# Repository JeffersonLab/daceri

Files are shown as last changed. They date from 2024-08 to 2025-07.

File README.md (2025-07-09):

# robot-project
Any and all code for the DACERI (DAta CEnter Robot Inspector) project in affiliation with Jefferson Lab.

## Example Video
[Demonstration of the Robot](https://www.youtube.com/watch?v=JDuZJEAZcf4&t=47s)

## Links
- [Parts List](https://docs.google.com/spreadsheets/d/1oFqTVsd3Hdgb1OTtmRurlVj-2fMQM05GRbAsK3FwgG0/edit?usp=sharing)
- [Thesis](https://drive.google.com/file/d/1kZYvtbdwQk6LjgCDchcMXePofmcdOxIe/view?usp=sharing)

## Run Simulation
1. Download the respective file based on OS and architecture: [https://github.com/google-deepmind/mujoco/releases](https://github.com/google-deepmind/mujoco/releases/latest)
2. Extract the file, and run **simulate** inside the extracted folder. Mujoco simulator should run
3. Clone this repository
4. Go into the **sim/** directory
5. Drag-and-drop any .xml into the simulator

## Edit/Print 3D model parts
1. Clone this repository
2. Go into the **designs/** directory
3. Choose any design you'd like
4. Open in any CAD software, make changes, and export as STL
5. Use a program like [UltiMaker Cura](https://ultimaker.com/software/ultimaker-cura/) or [Prusa Slicer](https://github.com/prusa3d/PrusaSlicer/releases) and slice the STL file into GCODE
6. Run the GCODE file on a 3D printer

## Move the robot
1. Clone this repository on both the client computer and the robot's R-Pi
2. On the robot's R-Pi, run the following steps according to your desired setup:
   * Run this first:
     ```
     python -m venv ./.venv --system-site-packages
     pip install -r /path/to/daceri/libs/requirements.txt
     source ./.venv/bin/activate
     ```
   * UDP Server (Modify the IP Address in the udp-server.py file to the IP of the R-Pi):
     ```
     python /path/to/daceri/scripts/udp-server.py
     ```
   * Websockets Server:
     ```
     python /path/to/daceri/scripts/websockets.py
     ```
4. Go into the **scripts/** directory
5. Use the provided Dockerfile ([Wiki: How to download and install Docker](https://docs.docker.com/get-started/get-docker/)) to automatically setup the correct packages and libraries or use a Linux/MacOS system with Python installed
   * Container:
     ```
     cd ./robot-project
     docker build -t robot-container .
     docker run -v `pwd`:/work/robot:Z -v /dev/input:/dev/input:ro --rm -it robot-container:latest
     ```
   * Host System (Linux/MacOS):
     ```
     python -m venv --system-site-packages ./.venv
     source ./.venv/bin/activate
     pip install -r /path/to/daceri/libs/requirements.txt
     ```
4. Plug in a controller (OS-dependent; usually [Linux](https://www.linuxmint.com/) works the best)
5. Run the RobotController.py file (under the **scripts/** subdirectory) with the desired connection type:
   * Serial (Controller is plugged into the Raspberry Pi):
     ```
     python RobotController.py s
     ```
   * Websockets:
     ```
     python RobotController.py w [R-Pi IPv4 address]
     ```
   * UDP Sockets:
     ```
     python RobotController.py u [R-Pi IPv4 address]
     ```
7. Press the **right** joystick to activate the motors
8. Start moving the joysticks to move the robot!

Use the Logitech F310 Game Controller connected to the local RaspPi 4B and control the JLab DACERI robot with the [REV Control Hub](https://www.revrobotics.com/rev-31-1595/).

## External Modules
```bash
git submodule update --init  # Clone the submodules
```

- `hiddapi`: The underlying system-level support for python package `hid`. After `dnf/apt install hid`, if you still see the python import error such as cannot find certain *.so/*.dll files, you will need to compile and install the `hidapi` library by your self. Follow the docstrings in [detect_joystick.py](./scripts/detect_joystick.py) to see the process.

- `REVHubInterface`: The Python module for the REV Control Hub. By running `python -m REVHubInterface`, you should be able to see a GUI that can take the inputs from the GUI and control the Robot motors.

## Scripts
- [motor_test.py](./scripts/motor_test.py): Control one of the wheels (motors) with `REVHubInterface` without launching the GUI. If succeeded, the wheel will run for 3 seconds.
- [detect_joystick.py](./scripts/detect_joystick.py): Use the Python `hid` library to detect the Logitech F310 Game Controller, translate its inputs to a string and print the string to the screen.

### Notes
#### **Fix the `/dev/hidraw*` permission**

If you can print the gampad's vendor id and product id to the screen but it raises `HIDException` "Unable to open device", that is related to the permission for the device.

Check it with `ls -l /dev/hidraw*` (`hidraw1` in our case). If it’s owned by `root` or another group, the user can’t access it. Fix it by:

1. Create a udev rule: `sudo nano /etc/udev/rules.d/99-logitech-f310.rules`
2. In this rule file, add:
    ```
    SUBSYSTEM=="hidraw", ATTRS{idVendor}=="046d", ATTRS{idProduct}=="c216", MODE="0666"
    ```
   Replace the `idVendor` and `idProduct` with the HEX outputs of the Python file.
3. Reload the rule
    ```bash
    sudo udevadm control --reload
    sudo udevadm trigger
    ```

Rerun the Python script and the `HIDException` error should be gone.

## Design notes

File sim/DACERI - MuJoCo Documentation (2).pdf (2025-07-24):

# MujoCo Documentation and Guide for Project DACERI

Evan Xu

## Overview

This document serves as a guide to using the MuJoCo simulation software, particularly as it

applies to the DACERI project.

MuJoCo is an open-source physics engine owned by Google DeepMind. The software is

designed for scientific purposes and is widely used for robotics simulation. MuJoCo loads .xml

files in its native modeling format, MJCF.

For the purposes of this project, MuJoCo serves as a virtual testing environment to provide

kinematic data and predict failure conditions, ultimately informing robot design decisions. The

DACERI project then uses a Python script to load the models, interface with a game controller,

and access MuJoCo simulation data for graphing. The .xml files for the robot utilize 3d models

of various components for a more accurate simulation.

## Tutorials

Getting Started:

1. For installation: https://mujoco.org/
2. Series of basic tutorials (YouTube):

https://youtube.com/playlist?list=PLc7bpbeTIk760SRoSDHfqi07RHa0Yv-bx&si=e12Bf3

rdntKjwAvK (https://youtube.com/playlist?list=PLc7bpbeTIk760SRoSDHfqi07RHa0Yv-bx&si=e12Bf3rdntKjwAvK)

3. XML reference: https://mujoco.readthedocs.io/en/stable/XMLreference.html#body-geom
4. GitHub: https://github.com/google-deepmind/mujoco

DACERI simulation:

1. Follow the README in the DACERI GitHub repository:

https://github.com/JeffersonLab/daceri

## How-To Guides/Troubleshooting

Importing 3d models (.stl):

Prior to <worldbody>:

<asset>
<mesh name="3D_MODEL_NAME" file="3D_MODEL.stl" /> </asset>
To create body:

<body name="#D_MODEL" pos="0 0 0"> <geom type="mesh" mesh="3D_MODEL_NAME" condim="3" friction="1 0.005 0.0001" rgba="0.6 0.4 0.2 1" euler="90 135 0"/> </body>

Adjusting robot movement speed:

Modify the magnitude of the “limit” variable in simulate-robot.py

Inertial tensors:

Use diaginertia (Ixx, Iyy, Izz) for diagonal tensor, and “fullinertia” (Ixx, Iyy, Izz, Ixy, Ixz, Iyz)

for full tensor (with MuJoCo versions 2.3+).

Mjpython:

Mac users: run simulate-robot.py from the terminal using the below command (example uses

anaconda3)

/opt/anaconda3/bin/mjpython "FILE_PATH/simulate-robot.py"

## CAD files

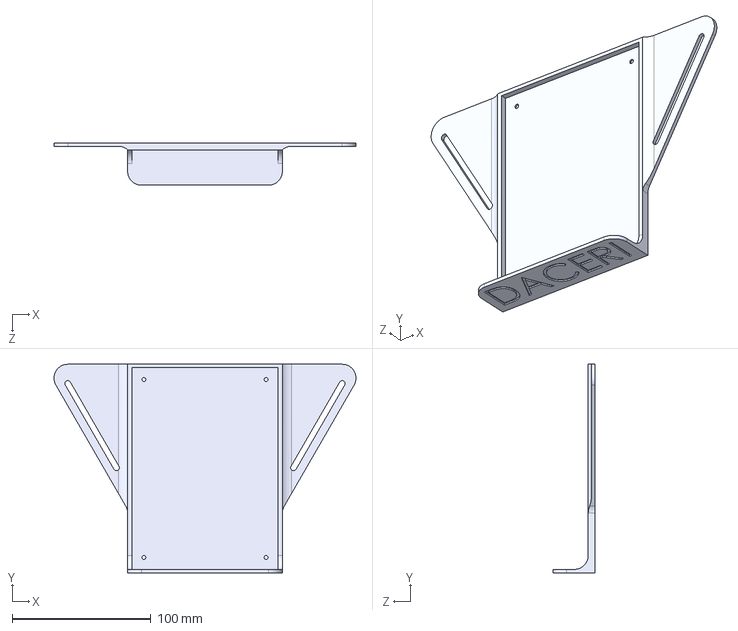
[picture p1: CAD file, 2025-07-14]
designs/Base/RevHubMount.STEP
217.4 x 150.1 x 30.5 mm

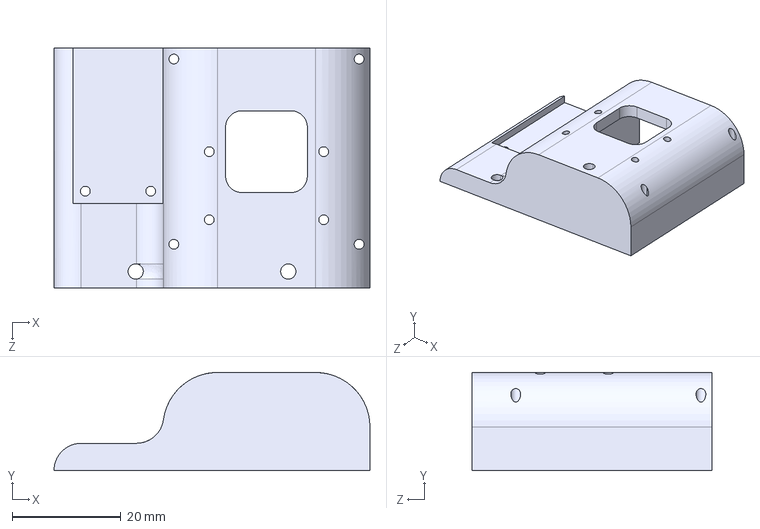
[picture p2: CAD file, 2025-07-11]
designs/Elevator/CameraMount.STEP
58.0 x 18.0 x 44.0 mm

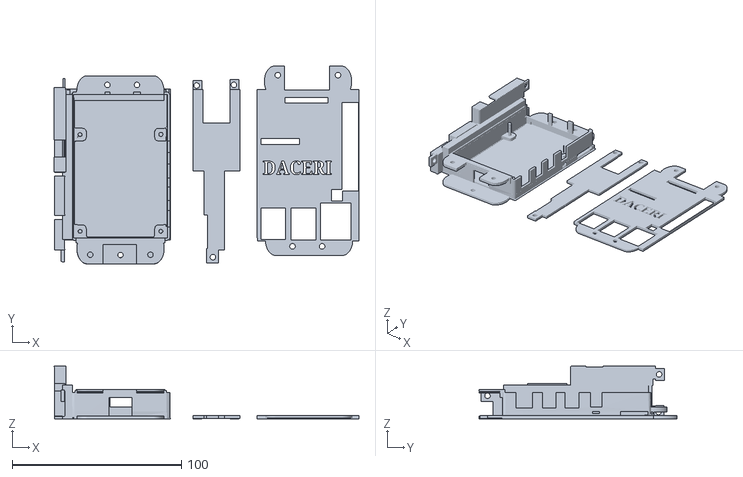
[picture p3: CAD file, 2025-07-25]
designs/Final Panel Set (7.24.25).stl
180.2 x 116.9 x 31.3

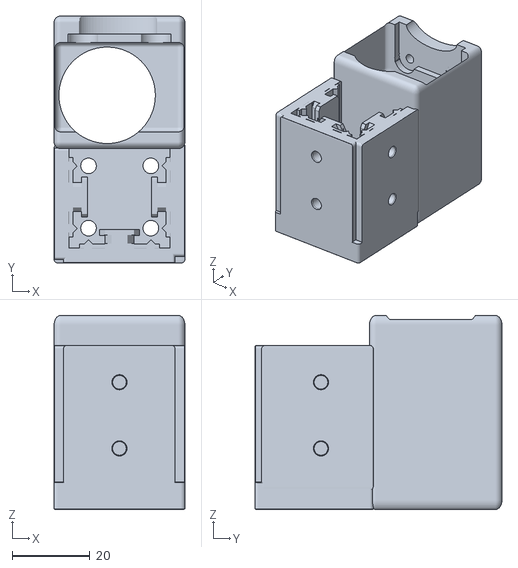
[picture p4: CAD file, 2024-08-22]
designs/goRailMotorMount/goRailMotorMount.obj
33.6 x 63.4 x 49.9

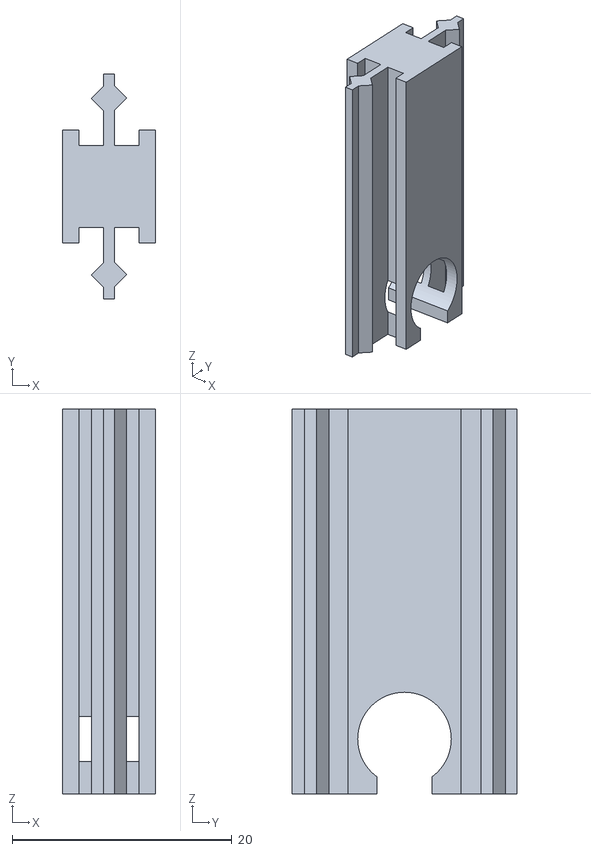
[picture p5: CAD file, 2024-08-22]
designs/goRailSlider/goRailSlider.obj
8.50 x 20.5 x 35.0

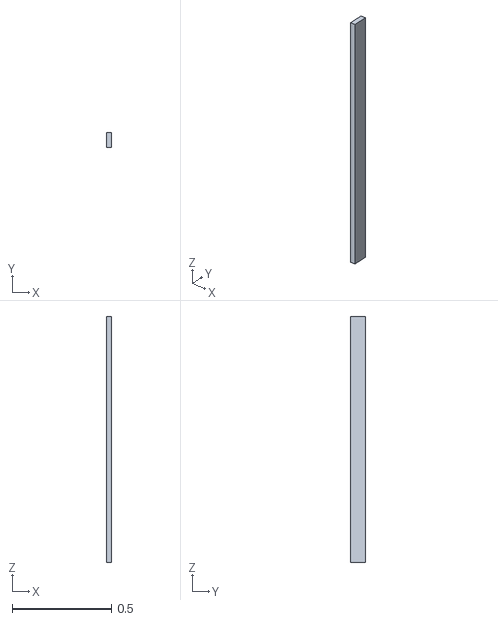
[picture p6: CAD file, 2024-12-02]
sim/stl_exports/elevator-extended-new.stl
0.0253 x 0.0763 x 1.24

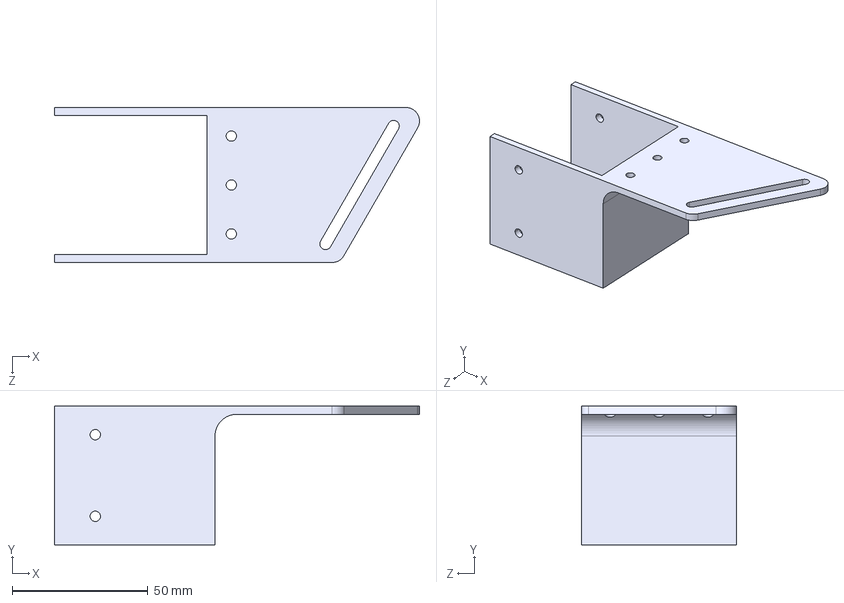
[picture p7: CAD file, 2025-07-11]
designs/Base/BatteryMountCase(Part1).STEP
134.2 x 51.0 x 57.0 mm

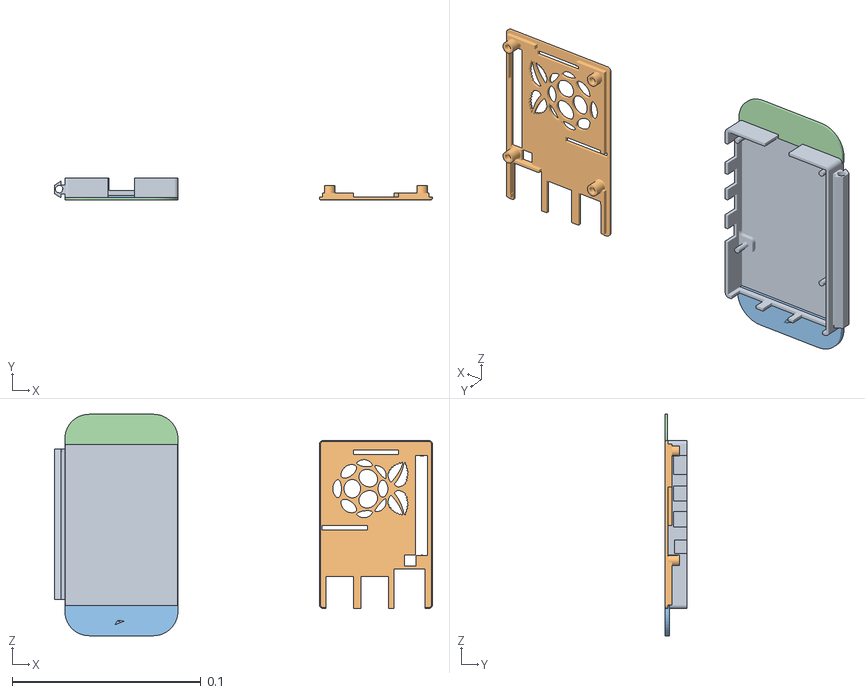
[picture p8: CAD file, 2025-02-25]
designs/Elevator/raspi-mount.obj
0.2 x 0.0115 x 0.117
r_pi_4_b_case
r_pi_4_b_lid

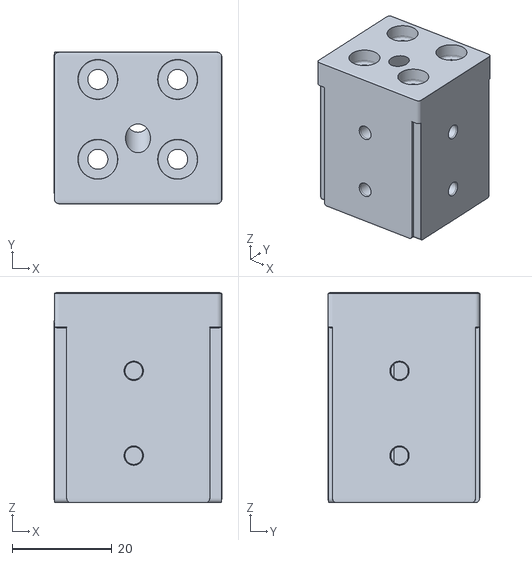
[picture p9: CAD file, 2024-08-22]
designs/goRailMotorMount/goRailEndcap.obj
33.6 x 30.4 x 42.1

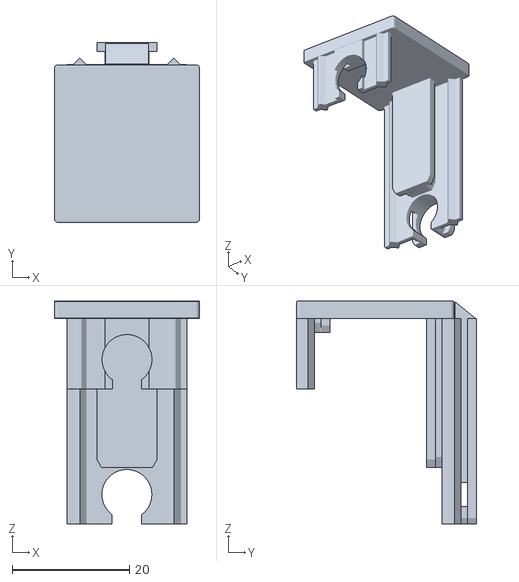
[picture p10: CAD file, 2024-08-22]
designs/goRailSlider/goRailSliderEndcap.obj
24.8 x 30.6 x 38.0

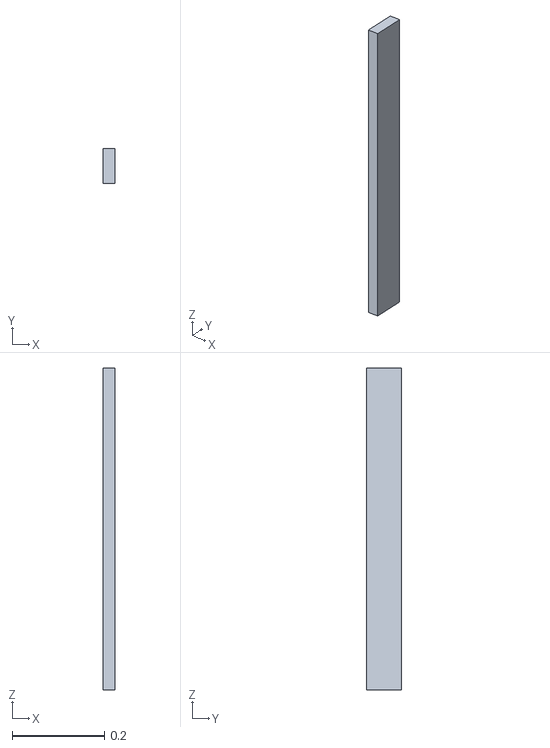
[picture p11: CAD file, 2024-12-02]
sim/stl_exports/elevator-collapsed-new.stl
0.0253 x 0.0763 x 0.699

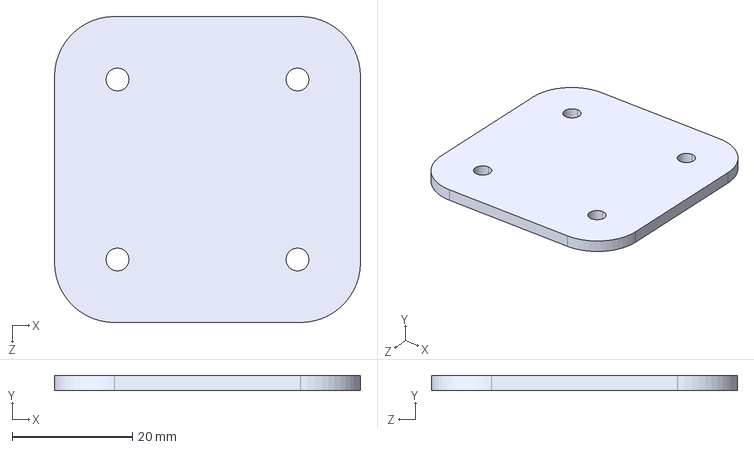
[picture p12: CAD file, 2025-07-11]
designs/Base/BatteryMountConnector.STEP
51.0 x 2.50 x 51.0 mm

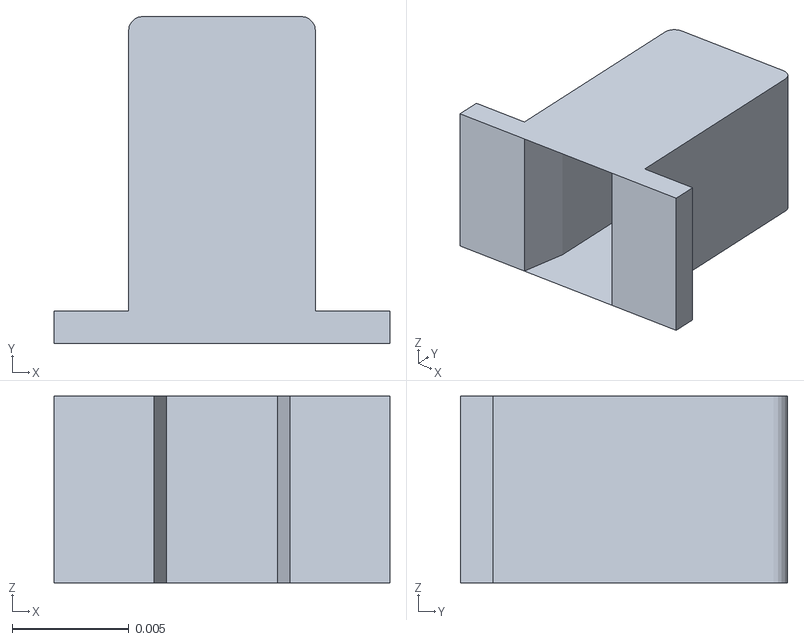
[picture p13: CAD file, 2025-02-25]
designs/Elevator/cable_guides_elev.obj
0.0144 x 0.014 x 0.008

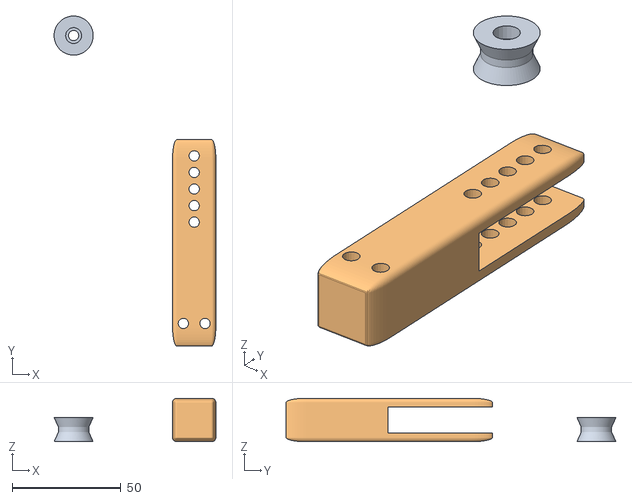
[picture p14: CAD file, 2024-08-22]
designs/goRailMotorMount/wireGuide.obj
74.5 x 151.9 x 20.0

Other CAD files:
sim/stl_exports/baseplate_robot-new.stl
designs/Base/BatteryMountCase(Part2).STEP
designs/Elevator/sensor_holder_elev.obj
sim/stl_exports/elevator-extended.stl
designs/Base/rev_control_hub_holder.obj
designs/Base/robot_base.obj
designs/Base/robot_base_elevator_holder.obj
sim/stl_exports/elevator-collapsed.stl

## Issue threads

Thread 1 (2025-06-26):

Solder new connectors on motors

faustus123, 2025-06-26:
At least 3 of the motor xt connectors have exposed wiring and need to be replaced with proper insulation. The Fast Electronics Lab will help with this.

[ ] Solder new connectors on motors
[ ] Add new labels to motor cables "M1", "M2", "M3" for wheels and "L0" for lifter
[ ] Add labels to xt -> JT connectors that match motor cables
[ ] Add matching labels to REVHub controller
[ ] Replace "A", "B", "C" labels on motor mounts with corresponding "M1", "M2", "M3" labels
[ ] Add "L0" label to lifter motor

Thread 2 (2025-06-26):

Fix camera mechanics

faustus123, 2025-06-26:
The cameras need to be remounted on the gimbal and the wiring fixed so that it allows the lifter to extend fully. The current mounting bracket was designed for a different camera so will need to be redesigned and printed.

- [x] Redesign the camera mount and print. (Make backup copy)
- [x] Mount both regular camera and thermal camera on gimbal
- [ ] Route servo cables to allow full extension of lifter. (They may need to be extended)

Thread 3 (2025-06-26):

Redesign and print RPi4 holder

faustus123, 2025-06-26:
The RPi4 holder is a 3D print that has a cover that does not stay on properly. There are also 3 small boards (2 sensor, one communication) mounted very close to it. The RPi4 holder design should be modified to fix the cover issue, but also to integrate the mounting of the 3 small boards so they are not mounted independently on the robot.

- [x] Fix design of RPi4 so cover stays on without tape
- [x] Add mounting points for 3 small boards
- [x] Print 3D holder and mount all pieces
- [x] Print backup copy of holder once design is finalized and tested
- [x] Commit revised design to repository

Closed 2025-07-25.

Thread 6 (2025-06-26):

Design holders for REVhub and battery

faustus123, 2025-06-26:
A piece needs to be designed and 3D printer that holds the REVHub in place on the robot. This may require modifying one of the base plates to integrate the holder.

The battery also needs to be held in place. The design for that must allow easy installation and removal of the battery.

- [x] Design mechanism for holding REVHub to robot base plate and 3D print
- [x] Design mechanism for holding battery to robot base plate and 3D print
- [x] Commit designs to repository

Closed 2025-07-11.

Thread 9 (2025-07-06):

Drive the robot

faustus123, 2025-07-06:
Fix any issues with the software, networking, cabling, etc. to allow the robot to be driven at JLab. Document the exact procedure in a .md file on the daceri github site. Do not assume the RPi or user's PC have any of the daceri software or support packages installed.

 - [ ] Fix all issues so robot is drivable
 - [ ] Document software installation procedures
 - [ ] Document procedure for starting software on both RPi and PC so it becomes actively drivable

veeraanand08, 2025-07-31:
Deadbands and Limits to prevent command lag and delay were implemented. Better descriptions are in the 25SU_SRGS Final Student Presentation.  The current working code is stored on RPI and needs to be moved to Main.

Next Steps:
- [ ] Wireless Control Testing
- [ ] Possible use of threading to prevent lag and delay
- [ ] Documentation - Installation and Start Drive

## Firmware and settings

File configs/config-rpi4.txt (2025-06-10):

# Place under /boot/firmware/config.txt

# For more options and information see
# http://rptl.io/configtxt
# Some settings may impact device functionality. See link above for details

# Uncomment some or all of these to enable the optional hardware interfaces
dtparam=i2c_arm=on,i2c_arm_baudrate=400000
dtoverlay=i2c6
dtoverlay=i2c5
#dtparam=i2s=on
#dtparam=spi=on

# Enable audio (loads snd_bcm2835)
dtparam=audio=on

# Additional overlays and parameters are documented
# /boot/firmware/overlays/README

# Automatically load overlays for detected cameras
camera_auto_detect=1

# Automatically load overlays for detected DSI displays
display_auto_detect=1

# Automatically load initramfs files, if found
auto_initramfs=1

# Enable DRM VC4 V3D driver
dtoverlay=vc4-kms-v3d
max_framebuffers=2

# Don't have the firmware create an initial video= setting in cmdline.txt.
# Use the kernel's default instead.
disable_fw_kms_setup=1

# Run in 64-bit mode
arm_64bit=1

# Disable compensation for displays with overscan
disable_overscan=1

# Run as fast as firmware / board allows
arm_boost=1

[cm4]
# Enable host mode on the 2711 built-in XHCI USB controller.
# This line should be removed if the legacy DWC2 controller is required
# (e.g. for USB device mode) or if USB support is not required.
otg_mode=1

[all]

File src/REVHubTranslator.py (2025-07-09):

"""
This module provides classes and methods to interface with REVHub motor controllers
and translate GamePad inputs into motor control commands.
"""

import math


MOTOR_NUM = 3
MOTOR_INIT_SPEED = -1.0
MOTOR_POWER_TO_SPEED_FACTOR = 32000

# The pulse width for the servo is in the range of 0.75ms to 2.25ms
SERVO_PULSE_MIN = 0.75
SERVO_PULSE_MAX = 2.25
SERVO_PULSE_RANGE = SERVO_PULSE_MAX - SERVO_PULSE_MIN

class ServoInput:
    """Represents the input for a single servo, including its ID and position."""
    def __init__(self, sid=-1):
        """
        Initialize a ServoInput instance.
        Args:
            sid (int): Servo ID.
        """
        self.sid = sid
        self.pos = 0.0  # the relative position of the servo pulse width

    def get_pulse_width(self, pos):
        """
        Update the pulse width based on the current position.
        """
        return pos * SERVO_PULSE_RANGE + SERVO_PULSE_MIN


class REVServoInputs:
    """Manages inputs for multiple servos on the robot."""
    def __init__(self):
        # Match David's code at
        #  https://github.com/faustus123/HLRobotController/blob/main/scripts/tri_wheel_robot.py
        self.inputs_dict = {}
        for sid in [0, 1, 4, 5]:
            self.inputs_dict['S' + str(sid)] = ServoInput(sid)

    def update_servo_position(self):
        """
        Update the pos for each servo based on GamePad inputs.
        """
        for _, servo_input in self.inputs_dict.items():
            # Ensure the position is within the valid range [0.0, 1.0]
            servo_input.pos = max(servo_input.pos, 0.0)
            servo_input.pos = min(servo_input.pos, 1.0)

    def print_inputs(self):
        """
        Print the current servo inputs, including servo IDs and period increments.
        """
        print("\nServo inputs:")
        for key, servo_input in self.inputs_dict.items():
            print(f"\t{key}: pos={servo_input.pos}")


class MotorInput:
    """Represents the input for a single motor, including its ID and speed."""
    def __init__(self, mid=-1):
        """
        Initialize a MotorInput instance.

        Args:
            mid (int): Motor ID. Valid IDs are 0, 1, and 2. Defaults to -1.
        """
        self.mid = mid  # Motor id. For our robot, the valid motor id can be 0, 1, 2
        # A float number can be negative. Negative number means opposite direction.
        self.speed = MOTOR_INIT_SPEED


class REVMotorInputs:
    """Manages inputs for multiple motors on the robot."""
    def __init__(self):
        """
        Initialize the motor controller inputs with a predefined number of motors.
        """
        self.inputs = []
        for i in range(MOTOR_NUM):
            self.inputs.append(MotorInput(i))

    def print_inputs(self):
        """
        Print the current motor inputs, including motor IDs and speeds.
        """
        for i in self.inputs:
            print(f"Motor input: ID = {i.mid}, Speed = {i.speed}")


class REVHubInputsTranslator:
    """
    Translates GamePad inputs into motor control commands for the REVHub.

    This class processes raw GamePad reports, calculates joystick values,
    and generates motor speed inputs based on the joystick movements.
    """
    def __init__(self):
        """
        Initialize the translator with default states for joystick values
        and motor inputs.
        """
        self.raw_state = {}
        self.last_joy_values = [-1.0, -1.0, -1.0, -1.0]
        self.curr_joy_values = self.last_joy_values

        self.last_motor_speeds = [MOTOR_INIT_SPEED , MOTOR_INIT_SPEED , MOTOR_INIT_SPEED ]
        self.curr_motor_inputs = REVMotorInputs()

        self.curr_servo_inputs = REVServoInputs()

    def get_raw_state_from_report(self, gpd_report):
        """
        Parse the raw GamePad report and update the internal state.

        Args:
            gpd_report (list): A list of bytes representing the GamePad report.
        """
        self.raw_state['left_joy_H'] = max( (float(gpd_report[0])-128.0)/127.0, -1.0)
        self.raw_state['left_joy_V'] = max( (float(gpd_report[1])-128.0)/127.0, -1.0)
        self.raw_state['right_joy_H'] = max( (float(gpd_report[2])-128.0)/127.0, -1.0)
        self.raw_state['right_joy_V'] = max( (float(gpd_report[3])-128.0)/127.0, -1.0)
        dpad = gpd_report[4] & 0b00001111
        self.raw_state['dpad_up'   ] = (dpad==0) or (dpad==1) or (dpad==7)
        self.raw_state['dpad_down' ] = (dpad==3) or (dpad==4) or (dpad==5)
        self.raw_state['dpad_left' ] = (dpad==5) or (dpad==6) or (dpad==7)
        self.raw_state['dpad_right'] = (dpad==1) or (dpad==2) or (dpad==3)
        self.raw_state['button_X'] = (gpd_report[4] & 0b00010000) != 0
        self.raw_state['button_A'] = (gpd_report[4] & 0b00100000) != 0
        self.raw_state['button_B'] = (gpd_report[4] & 0b01000000) != 0
        self.raw_state['button_Y'] = (gpd_report[4] & 0b10000000) != 0
        self.raw_state['bumper_left'  ] = (gpd_report[5] & 0b00000001) != 0
        self.raw_state['bumper_right' ] = (gpd_report[5] & 0b00000010) != 0
        self.raw_state['trigger_left' ] = (gpd_report[5] & 0b00000100) != 0
        self.raw_state['trigger_right'] = (gpd_report[5] & 0b00001000) != 0
        self.raw_state['back'         ] = (gpd_report[5] & 0b00010000) != 0
        self.raw_state['start'        ] = (gpd_report[5] & 0b00100000) != 0
        self.raw_state['L3'           ] = (gpd_report[5] & 0b01000000) != 0
        self.raw_state['R3'           ] = (gpd_report[5] & 0b10000000) != 0

        self.is_motor_inputs_enabled()
        self.is_servo_inputs_enabled()

    def is_servo_inputs_enabled(self):
        """
        Check if servo inputs are enabled based on the GamePad state.
        """
        if self.raw_state['R3']:
            print("\nEnable all servos\n")

    def is_motor_inputs_enabled(self):
        """
        Check if motor inputs are enabled based on the GamePad state.
        """
        if self.raw_state['L3']:
            print("\nEnable all motors\n")

    def print_report_n_state(self, report):
        """
        Print the GamePad report and the parsed raw state.

        Args:
            report (list): A list of bytes representing the GamePad report.
        """
        print(report)
        self.get_raw_state_from_report(report)
        print(self.raw_state)
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

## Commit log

2024-08-22 3D models for goRail. (#1)
    [goRailEndcap.obj, goRailMotorMount.obj, goRailSlider.obj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]
2024-09-05 Add CamStream repository for Thermal and regular camera
2024-10-11 Update/rename simulation (one with controller support and the other with automated tests) and XMLs. Add STLs of elevator - collapsed and extended. Remove no longer needed 'entrypoint.sh'.
    [elevator-collapsed.stl, elevator-extended.stl]
2024-10-27 Update requirements.txt and add mpu6050 robot script to take data from onboard accelerometer, gyroscope, and temperature
2024-11-28 Rework graph on simulation script. BME280 temp, humidity, and pressure sensor support. Add check to make sure all four motors cannot power on due to L298N issue. Create new simulation XML with correc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
    [RobotController.py, bme280-script.py]
2024-12-02 Improve simulation by using actual mass, moment of inertia values, and other real values. Create new, updated STLs for accurate simulation. Recored position, velocity, and acceleration values after 1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
    [baseplate_robot-new.stl, elevator-collapsed-new.stl, elevator-extended-new.stl]
2025-01-23 Add utility to check i2c speed
2025-02-25 Add designs for the base, elevator holder, cable guides, r-pi mount, and sensor holder. Update submodules to use ssh
    [cable_guides_elev.obj, raspi-mount.obj, robot_base.obj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]
2025-03-19 Revert targeting PS4 controller support in RobotController.py
    [RobotController.py]
2025-03-31 Rylen's motor example
2025-03-31 motors with rev package
2025-04-02 added motor 4 and serovs
2025-04-03 Clean up motor_test.py
2025-04-03 Make robot_control.py print motor speeds
2025-04-04 Add Servo inputs
2025-04-04 Clean up motor_test.py more
2025-04-04 Add servo_test.py to print S0 info
2025-04-04 Add ms for print S0
2025-04-04 Add \n to REV module print
2025-04-30 updated motor contol file
2025-06-10 Update raspberry pi config
    [config-rpi4.txt]
2025-07-10 Create wiring diagram
2025-07-10 Rename wires.jpg to Online wires diagram
2025-07-10 Update and rename wiring diagram to __
2025-07-10 Add files via upload
    Hand-drawn wiring diagram
2025-07-11 Rev Control Hub Holder CAD
    [rev_control_hub_holder.obj]
2025-07-14 Updated CAD for Rev Control Hub Mount
    [RevHubMount.STEP]
2025-07-24 Expanded inertia tensors to full matrices
    The robot does not currently drive in the simulation due to a chain of positional issues caused by the value adjustments.
2025-07-25 Add files via upload
    Final RPi case design
    [Final Panel Set (7.24.25).stl]
